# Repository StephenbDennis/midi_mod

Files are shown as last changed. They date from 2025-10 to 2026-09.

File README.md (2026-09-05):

# Github Pages
https://stephenbdennis.github.io/midi_mod/

# Modular USB MIDI Controller (Midi-Mod)

A **USB MIDI device** that supports up to **3 hot-swappable input modules**, configurable as **buttons**, **sliders**, or **potentiometers**.  
I was going for a compact design that allowed the user to configure their Midi-Mod device without needing firmware updates.
* Note: This is a work in progress... It's working, but there are many things that could be improved.

---

## Configure it in a browser

**[stephenbdennis.github.io/midi_mod](https://stephenbdennis.github.io/midi_mod/)**

Pick a message for every input and watch the MIDI bytes it will put on the wire. There is a preset
per module type (Buttons, Sliders, Pots), it imports a config you already have, and it can listen to
the device over Web MIDI so you can check what it is actually sending. Everything runs in the
browser; nothing is uploaded.

**Connect** pairs with the device over Bluetooth. From there **Load from device** pulls the config
that is on it right now, and **Send to device** writes `config.toml` back and applies it
immediately &mdash; no replug, and the device stays a USB MIDI interface throughout, so you can keep
playing into a DAW while you edit. Transfers are checksummed in both directions and rejected if they
do not match.

Bluetooth needs Web Bluetooth, so it is Chrome, Edge and Opera only (on Linux you may have to enable
it in `chrome://flags`). Everywhere else, Download still gives you the same `config.toml`.

---

### Project Build and Flash

Needs **ESP-IDF 5.2 or newer**. Dependencies come from `dependencies.lock`; `idf.py` fetches them
on the first build.

```
idf.py set-target esp32s3
idf.py build
idf.py -p COM<xxx> flash
idf.py -p COM<xxx> monitor
```

---

## Features

- **Up to 3 modules active at once**
- Modules can be:
  - Button Module (5 Cherry Mx buttons)
  - Slider Module (2 Linear Potentiometers)
  - Pot Module (5 Knob Potentiometers)
- Modules can be **mixed** (e.g. 3 Button Modules or 1 Button + 1 Slider + 1 Pot)
- **Every MIDI message**: notes, aftertouch, control change, program change, pitch bend, and the
  system common and real time messages
- Configurable with onboard .toml(ish) file
- BLE config service, so it can be reconfigured while it plays

---

## Module Types

Each module occupies **one slot**.  
A maximum of **3 slots** are available.

### 1. Button Module
- Defaults to a digital device when connected

### 2. Slider Module
- Defaults to an analog device when connected
- Uses dual sliders, so device 1 and 2 should have the roughly the same value. and well as 3 and 4. Device 5 is tied to ground.

### 3. Potentiometer Module
- Defaults to an analog device when connected

---

## Configuration
- The device advertises over Bluetooth LE as **MIDI-Mod** whenever it is powered. Open the
  configurator, press Connect, and pick it from the browser's device chooser. There is no config
  boot mode any more: USB is the MIDI interface full time.

- **Send to device** writes `config.toml` into the device's internal filesystem and applies it on
  the next poll tick, so a change is audible straight away.

- `reference.txt` is written to the internal filesystem on first boot. It documents the config
  format, though the same reference is on the configurator page under **Message reference**.

- If no config.toml is present the device writes the example below, so there is always something to edit.

- A line starting with `#` is a comment. Numbers are hexadecimal.

### Module Options
- press_velocity : (Optional) 0x0-0x7F : Defaults to 0x7F
  - This is the note_on/note_off message velocity. Only used with buttons
- channel 	     : (Optional) 0x0-0xF  : Defaults to 0x0
  - The channel messages are sent on. (Part of the MIDI message)
- alpha	    	 : (Optional) 0.01-0.5 : Defaults to 0.3
  - This value changes the responsivity of the input. Higher is faster, Lower is smoother but slower. Currently buttons are analog reads, so this should be pretty high when using that module
### Device Options
- device_type          : (Optional) analog,digital                 : Defaults to module type
  - Digital: triggers message_on_change on the rising edge and message_on_stop on the falling edge. 
  - Analog:  triggers message_on_change when value is changing and message_on_stop when the value is no longer changing. 
- channel              : (Optional) 0x0-0xF,inherit                : Defaults to inherit
  - Overrides the module channel for this one input. System messages ignore it.
- message_on_change    : (Optional) see Messages below             : Defaults to noop
  - The message to send when the value changes (analog) or rising edge (digital). This can be a name or a status byte
- message_on_stop      : (Optional) see Messages below             : Defaults to noop
  - The message to send when the value stops changing (analog) or falling edge (digital). This can be a name or a status byte
- data 	               : (Optional) notes,0x0-0x7F                 : Defaults to 0x0. 
  - For messages that carry a note, controller or program number this will be the value in the message. This can be a note string or a hex value. Overwritten by Manual Data
- manual_data_change_0 : (Optional) 0x0-0x7F,dev                   : Not used if not set
  - If set this will set the first data byte on a change action to this value. If dev, the value of the device is used 
- manual_data_change_1 : (Optional) 0x0-0x7F,dev                   : Not used if not set
  - If set this will set the second data byte on a change action to this value. If dev, the value of the device is used
- manual_data_stop_0   : (Optional) 0x0-0x7F,dev                   : Not used if not set
  - If set this will set the first data byte on a stop action to this value. If dev, the value of the device is used
- manual_data_stop_1   : (Optional) 0x0-0x7F,dev                   : Not used if not set
  - If set this will set the second data byte on a stop action to this value. If dev, the value of the device is used

### Messages

`input` is the live 0-127 reading of the button, slider or knob. `data` is the device's `data` option.

| Name | Status | Bytes | Data 1 | Data 2 |
| --- | --- | --- | --- | --- |
| `noop` | - | 0 | nothing is sent | |
| `note_off` | 0x80 | 3 | note (data) | velocity (press_velocity) |
| `note_on` | 0x90 | 3 | note (data) | velocity (press_velocity) |
| `poly_aftertouch` | 0xA0 | 3 | note (data) | pressure (input) |
| `cc` | 0xB0 | 3 | controller (data) | value (input) |
| `pc` | 0xC0 | 2 | program (data) | |
| `channel_aftertouch` | 0xD0 | 2 | pressure (input) | |
| `pitch_bend` | 0xE0 | 3 | bend LSB (input) | bend MSB (input) |
| `mtc_quarter_frame` | 0xF1 | 2 | time code (data) | |
| `song_position` | 0xF2 | 3 | position LSB (input) | position MSB (input) |
| `song_select` | 0xF3 | 2 | song (data) | |
| `tune_request` | 0xF6 | 1 | | |
| `clock` | 0xF8 | 1 | | |
| `start` | 0xFA | 1 | | |
| `continue` | 0xFB | 1 | | |
| `stop` | 0xFC | 1 | | |
| `active_sensing` | 0xFE | 1 | | |
| `system_reset` | 0xFF | 1 | | |

- Aliases: `control_change` = `cc`, `program_change` = `pc`, `channel_pressure` = `channel_aftertouch`, `timing_clock` = `clock`
- A raw status byte such as `0x90` works in place of a name
- Messages from 0xF1 up are system messages and ignore the channel
- `pitch_bend` and `song_position` spread the 0-127 reading across their full 14 bit range

### Notes
`C_(-1..9)` `C#_(-1..9)` `D_(-1..9)` `D#_(-1..9)` `E_(-1..9)` `F_(-1..9)` `F#_(-1..9)` `G_(-1..9)` `G#_(-1..8)` `A_(-1..8)` `A#_(-1..8)` `B_(-1..8)`

### Example
```
[module1]
channel = 0x0
press_velocity = 0x7F
alpha = 0.5
[module1.device1]
message_on_change = note_on
message_on_stop = note_off
data = C_3
[module1.device2]
message_on_change = note_on
message_on_stop = note_off
data = D_3
[module1.device3]
message_on_change = note_on
message_on_stop = note_off
data = E_3
[module1.device4]
message_on_change = start
message_on_stop = stop
[module1.device5]
message_on_change = pc
data = 0x0

[module2]
channel = 0x0
alpha = 0.3
[module2.device1]
message_on_change = cc
data = 0x1
[module2.device2]
message_on_change = cc
data = 0x7
[module2.device3]
message_on_change = cc
data = 0xA
[module2.device4]
message_on_change = pitch_bend
[module2.device5]
message_on_change = channel_aftertouch

[module3]
channel = 0x1
alpha = 0.3
[module3.device1]
message_on_change = cc
data = 0x0
[module3.device2]
message_on_change = cc
data = 0x2
[module3.device3]
message_on_change = poly_aftertouch
data = C_3
[module3.device4]
message_on_change = cc
data = 0x4
[module3.device5]
message_on_change = cc
data = 0x5
```

---

## Repo layout

| Path | What it is |
| --- | --- |
| `main/` | ESP32-S3 firmware |
| `boards/` | KiCad projects for the main board and the three module types |
| `docs/` | The web configurator, published to GitHub Pages |
| `.github/workflows/pages.yml` | Deploys `docs/` on every push to `main` |

To turn the page on, set **Settings → Pages → Source** to **GitHub Actions**. (Deploying from the
`main` branch `/docs` folder works too, and needs no workflow.)

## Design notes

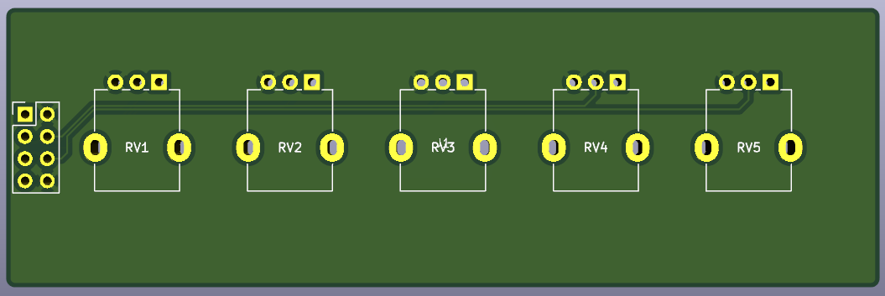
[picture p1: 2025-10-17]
images/midi-pot.png

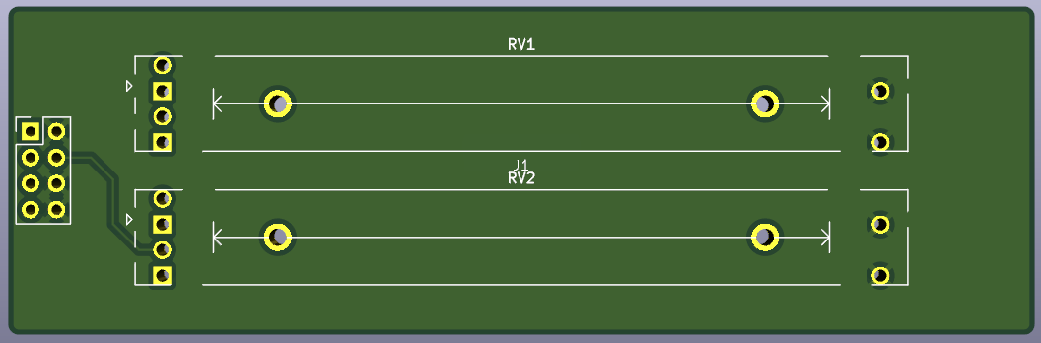
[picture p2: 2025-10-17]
images/midi-slide.png

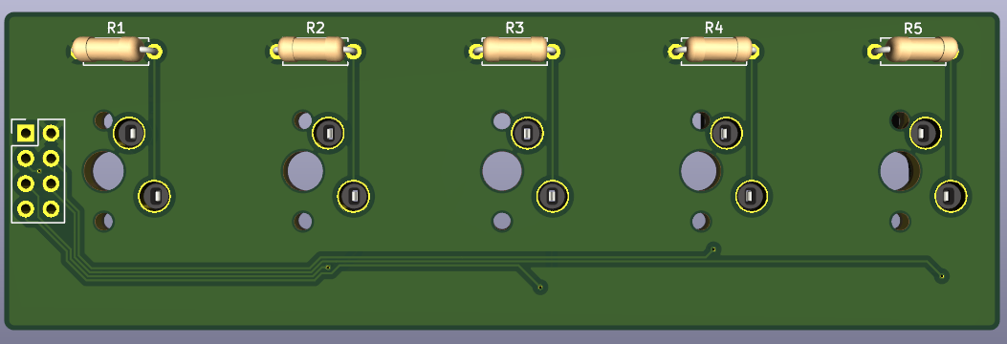
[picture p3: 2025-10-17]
images/midi-button.png

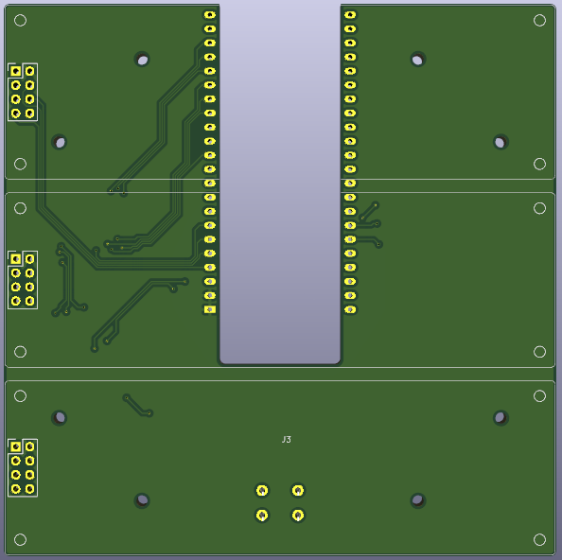
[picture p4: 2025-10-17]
images/midi-main.png

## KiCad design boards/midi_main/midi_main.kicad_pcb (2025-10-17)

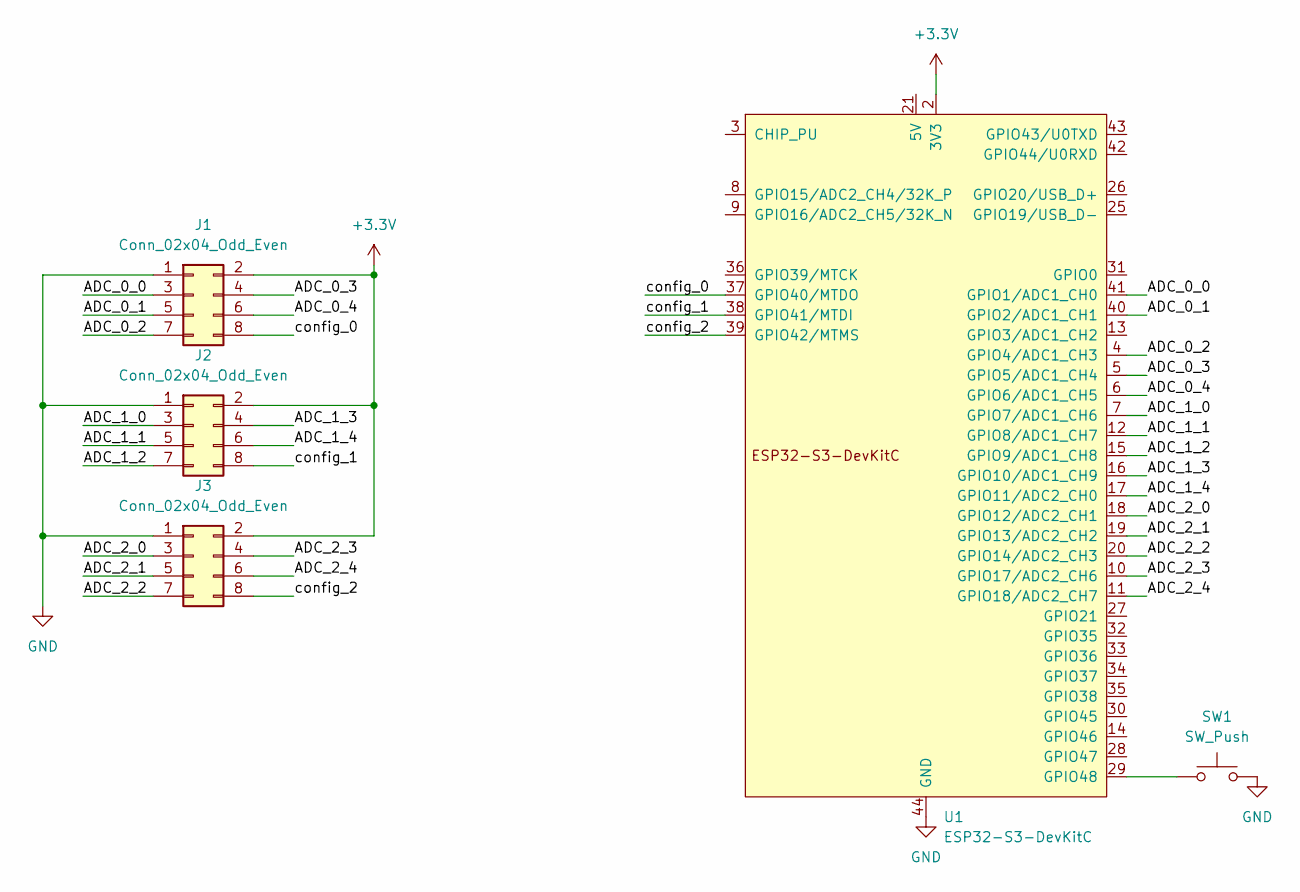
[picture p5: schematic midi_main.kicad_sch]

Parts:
J1, J2, J3: Conn_02x04_Odd_Even; MidiModuleOutline
SW1: SW_Push; SW_PUSH_6mm_H7.3mm
U1: ESP32-S3-DevKitC; ESP32-S3-DevKitC_Steve

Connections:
+3.3V: J1.2, J2.2, J3.2, U1.1 (3V3), U1.2 (3V3)
/ADC_0_0: J1.3, U1.41 (GPIO1/ADC1_CH0)
/ADC_0_1: J1.5, U1.40 (GPIO2/ADC1_CH1)
/ADC_0_2: J1.7, U1.4 (GPIO4/ADC1_CH3)
/ADC_0_3: J1.4, U1.5 (GPIO5/ADC1_CH4)
/ADC_0_4: J1.6, U1.6 (GPIO6/ADC1_CH5)
/ADC_1_0: J2.3, U1.7 (GPIO7/ADC1_CH6)
/ADC_1_1: J2.5, U1.12 (GPIO8/ADC1_CH7)
/ADC_1_2: J2.7, U1.15 (GPIO9/ADC1_CH8)
/ADC_1_3: J2.4, U1.16 (GPIO10/ADC1_CH9)
/ADC_1_4: J2.6, U1.17 (GPIO11/ADC2_CH0)
/ADC_2_0: J3.3, U1.18 (GPIO12/ADC2_CH1)
/ADC_2_1: J3.5, U1.19 (GPIO13/ADC2_CH2)
/ADC_2_2: J3.7, U1.20 (GPIO14/ADC2_CH3)
/ADC_2_3: J3.4, U1.10 (GPIO17/ADC2_CH6)
/ADC_2_4: J3.6, U1.11 (GPIO18/ADC2_CH7)
/config_0: J1.8, U1.37 (GPIO40/MTDO)
/config_1: J2.8, U1.38 (GPIO41/MTDI)
/config_2: J3.8, U1.39 (GPIO42/MTMS)
GND: J1.1, J2.1, J3.1, SW1.2, U1.22 (GND), U1.23 (GND), U1.24 (GND), U1.44 (GND)
unnamed: SW1.1, U1.29 (GPIO48)

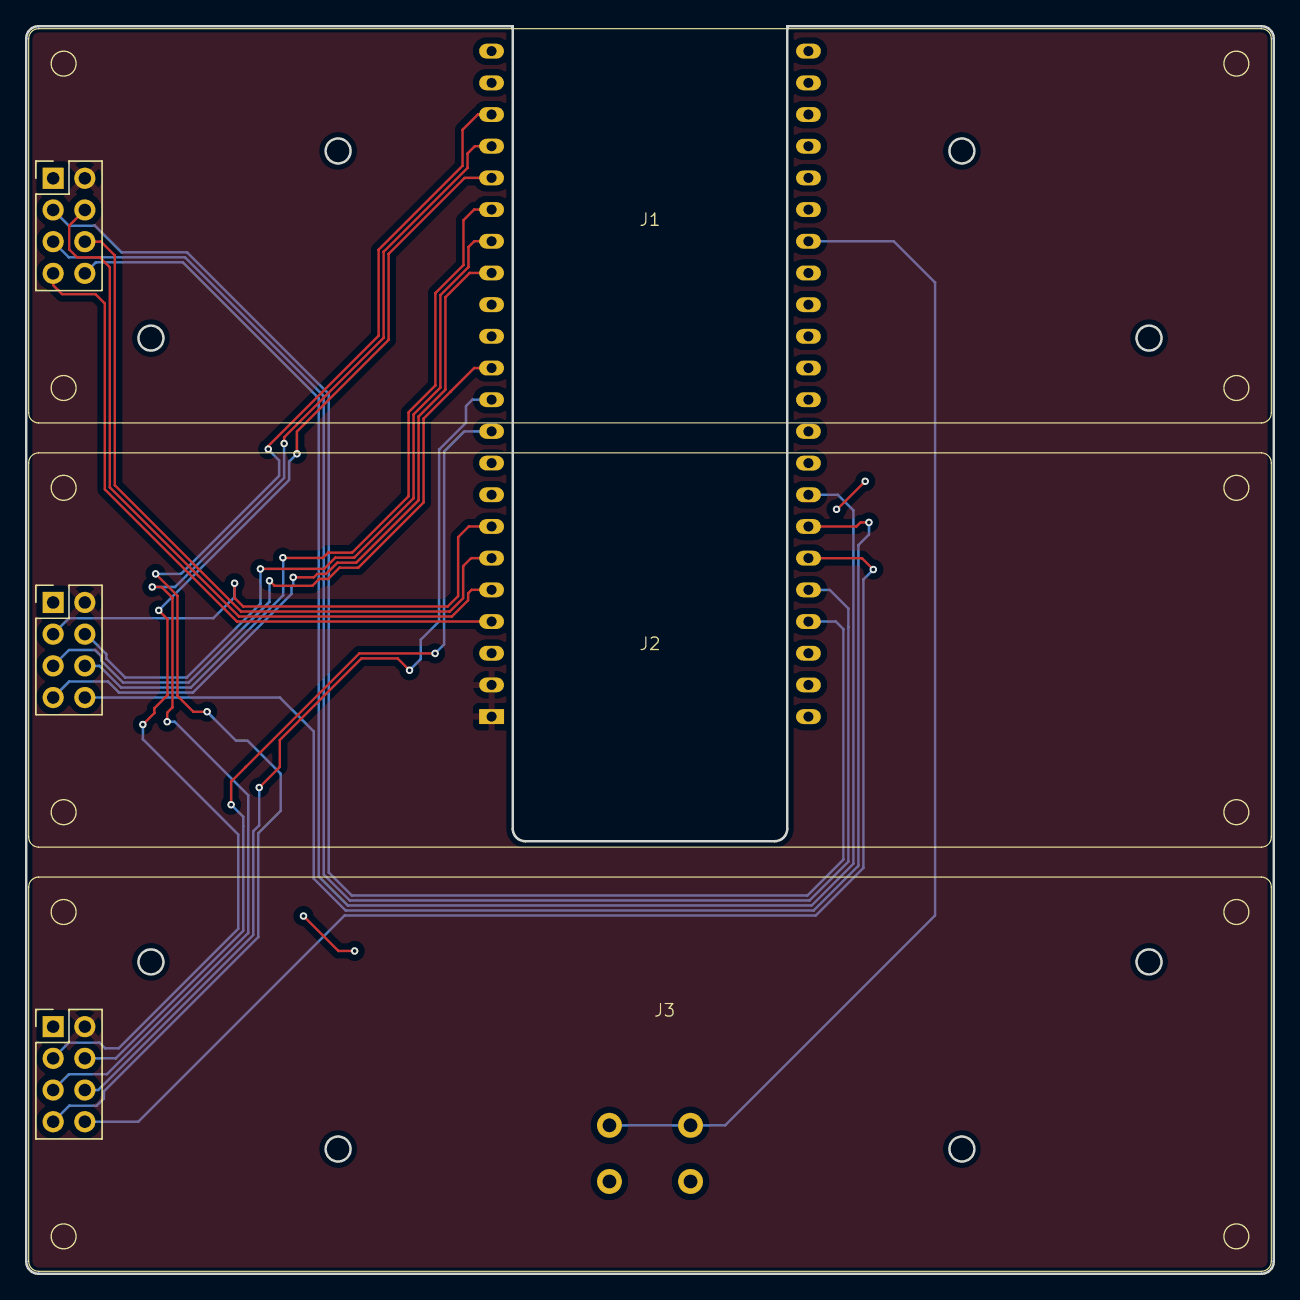
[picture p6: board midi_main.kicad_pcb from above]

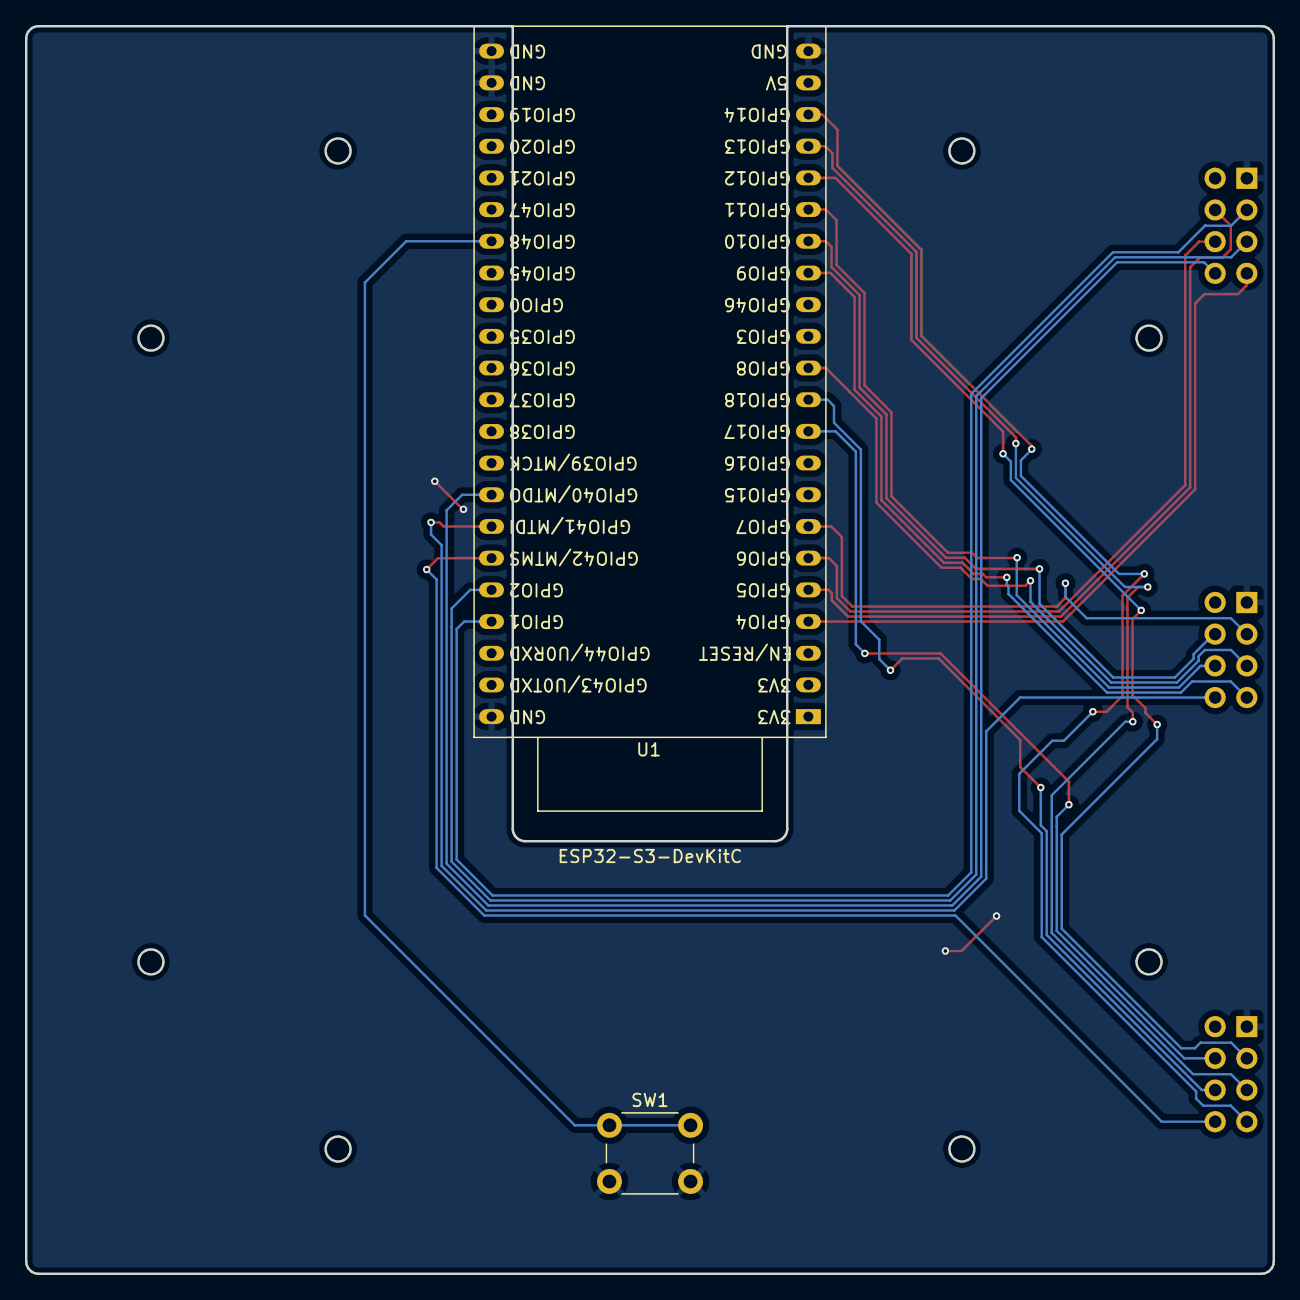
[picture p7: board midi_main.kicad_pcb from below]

Board: 2 copper layers, 100.0 x 100.0 mm, 5 parts (2 on the bottom side), 21 nets.

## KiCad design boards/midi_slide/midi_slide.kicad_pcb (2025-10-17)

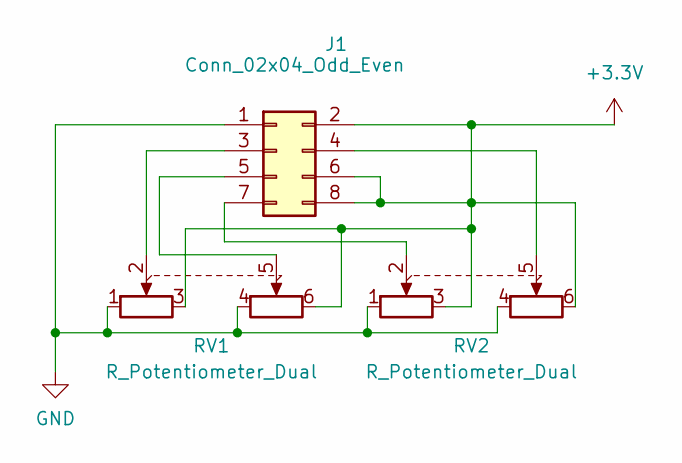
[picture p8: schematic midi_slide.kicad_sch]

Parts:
J1: Conn_02x04_Odd_Even; MidiModuleBase
RV1, RV2: R_Potentiometer_Dual; PS60M-0MC2BR10KN

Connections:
+3.3V: J1.2, J1.6, J1.8, RV1.3, RV1.6, RV2.3, RV2.6
GND: J1.1, RV1.1, RV1.4, RV2.1, RV2.4
unnamed: J1.3, RV1.2
unnamed: J1.4, RV2.5
unnamed: J1.5, RV1.5
unnamed: J1.7, RV2.2

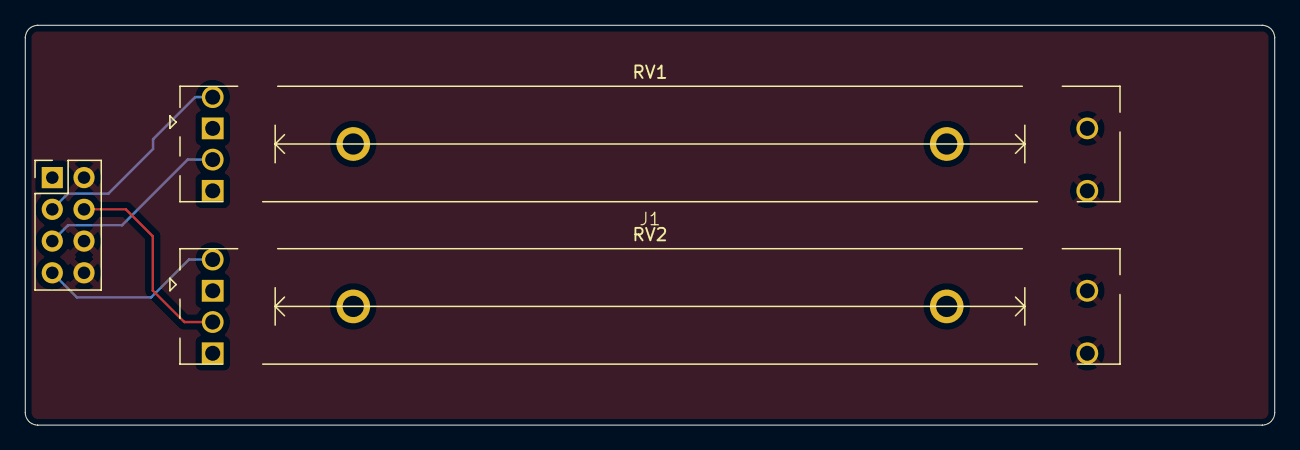
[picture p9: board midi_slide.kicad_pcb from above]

Board: 2 copper layers, 100.0 x 32.0 mm, 3 parts (0 on the bottom side), 6 nets.

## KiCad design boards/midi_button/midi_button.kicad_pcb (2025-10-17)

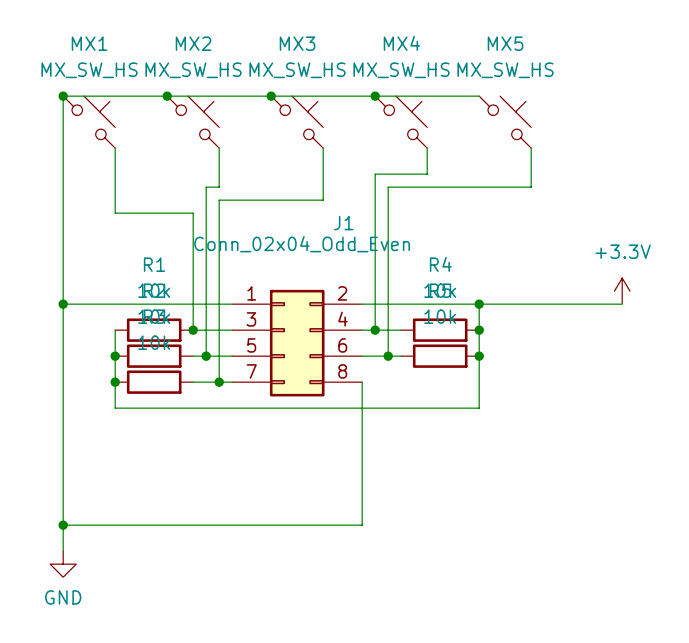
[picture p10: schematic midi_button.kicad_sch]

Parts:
J1: Conn_02x04_Odd_Even; MidiModuleBase
MX1, MX2, MX3, MX4, MX5: MX_SW_HS; SW_MX_HS_CPG151101S11_1u
R1, R2, R3, R4, R5: 10k; R_Axial_DIN0207_L6.3mm_D2.5mm_P7.62mm_Horizontal

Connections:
+3.3V: J1.2, R1.1, R2.1, R3.1, R4.2, R5.2
GND: J1.1, J1.8, MX1.1, MX2.1, MX3.1, MX4.1, MX5.1
unnamed: J1.3, MX1.2, R1.2
unnamed: J1.4, MX4.2, R4.1
unnamed: J1.5, MX2.2, R2.2
unnamed: J1.6, MX5.2, R5.1
unnamed: J1.7, MX3.2, R3.2

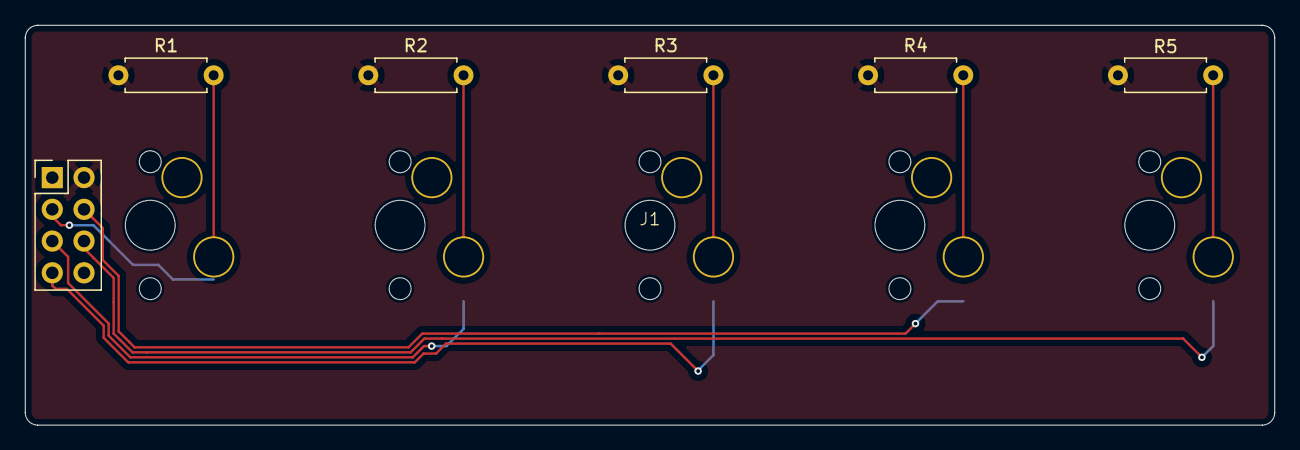
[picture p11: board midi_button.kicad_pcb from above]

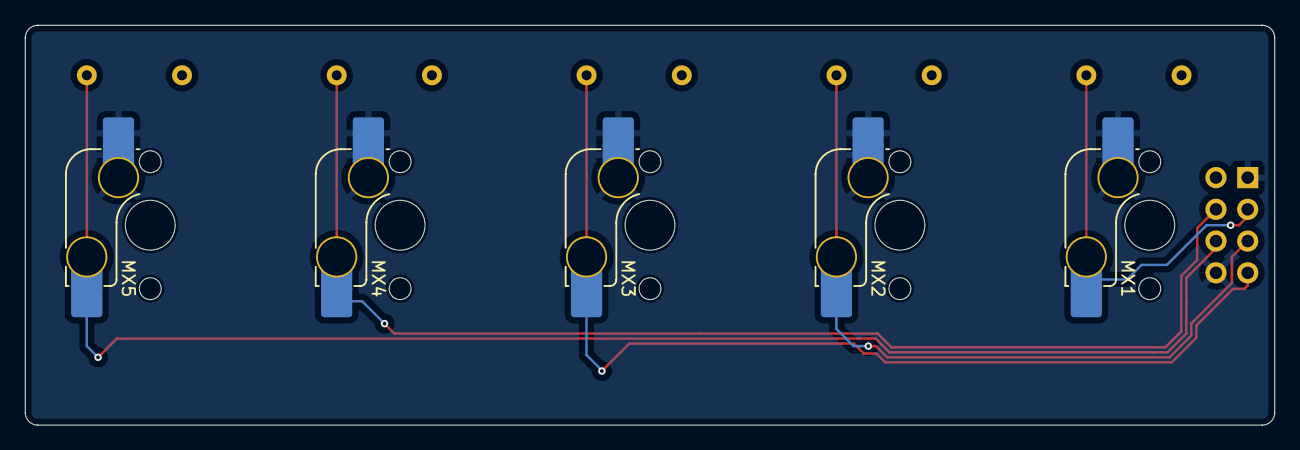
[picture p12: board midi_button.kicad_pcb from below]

Board: 2 copper layers, 100.0 x 32.0 mm, 11 parts (5 on the bottom side), 7 nets.

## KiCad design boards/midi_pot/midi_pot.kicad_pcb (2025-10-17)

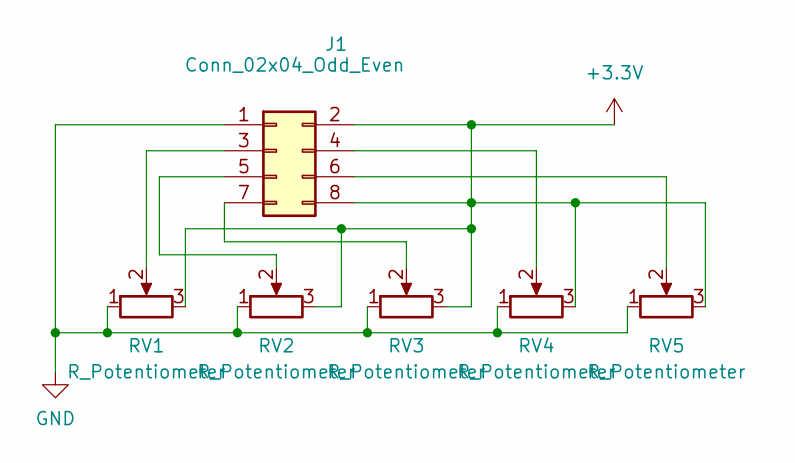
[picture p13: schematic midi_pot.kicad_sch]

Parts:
J1: Conn_02x04_Odd_Even; MidiModuleBase
RV1, RV2, RV3, RV4, RV5: R_Potentiometer; Potentiometer_Alpha_RD901F-40-00D_Single_Vertical_CENTER

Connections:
+3.3V: J1.2, J1.8, RV1.3, RV2.3, RV3.3, RV4.3, RV5.3
GND: J1.1, RV1.1, RV2.1, RV3.1, RV4.1, RV5.1
unnamed: J1.3, RV1.2
unnamed: J1.4, RV4.2
unnamed: J1.5, RV2.2
unnamed: J1.6, RV5.2
unnamed: J1.7, RV3.2

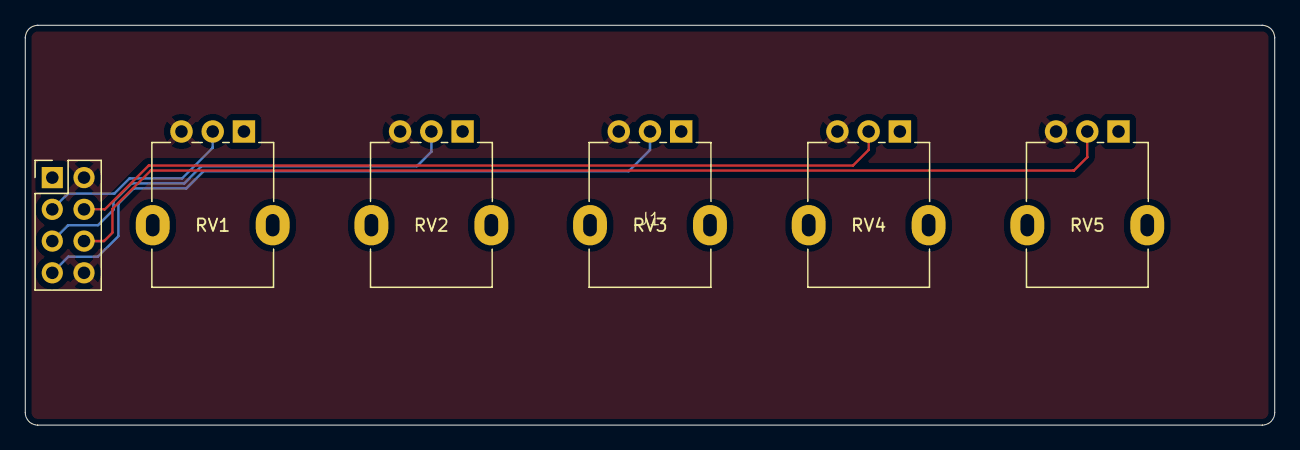
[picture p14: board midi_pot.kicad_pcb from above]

Board: 2 copper layers, 100.0 x 32.0 mm, 6 parts (0 on the bottom side), 7 nets.

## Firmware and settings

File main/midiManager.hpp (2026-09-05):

#include <stdlib.h>
#include <atomic>
#include <vector>
#include <unordered_map>
#include "driver/gpio.h"
#include "esp_adc/adc_oneshot.h"
#include "esp_adc/adc_cali.h"
#include "esp_adc/adc_cali_scheme.h"
#include "tinyusb.h"
#include "tinyusb_default_config.h"
#include "deviceInfo.hpp"

// --- Pin Mapping ---
// Common
#define MAIN_LED                GPIO_NUM_38     // GPIO38

// Device 1
#define ADC_0_0                 ADC_CHANNEL_0   // GPIO1
#define ADC_0_1                 ADC_CHANNEL_1   // GPIO2
#define ADC_0_2                 ADC_CHANNEL_3   // GPIO4
#define ADC_0_3                 ADC_CHANNEL_4   // GPIO5
#define ADC_0_4                 ADC_CHANNEL_5   // GPIO6
#define GPIO_DEVICE_1_SELECT    GPIO_NUM_40     // GPIO40

// Device 2
#define ADC_1_0                 ADC_CHANNEL_6   // GPIO7
#define ADC_1_1                 ADC_CHANNEL_7   // GPIO8
#define ADC_1_2                 ADC_CHANNEL_8   // GPIO9
#define ADC_1_3                 ADC_CHANNEL_9   // GPIO10
#define ADC_1_4                 ADC_CHANNEL_0   // GPIO11
#define GPIO_DEVICE_2_SELECT    GPIO_NUM_41     // GPIO41

// Device 3
#define ADC_2_0                 ADC_CHANNEL_1   // GPIO12
#define ADC_2_1                 ADC_CHANNEL_2   // GPIO13
#define ADC_2_2                 ADC_CHANNEL_3   // GPIO14
#define ADC_2_3                 ADC_CHANNEL_6   // GPIO17
#define ADC_2_4                 ADC_CHANNEL_7   // GPIO18
#define GPIO_DEVICE_3_SELECT    GPIO_NUM_42     // GPIO42

// TinyUSB Settings
#define TUSB_DESCRIPTOR_TOTAL_LEN (TUD_CONFIG_DESC_LEN + CFG_TUD_MIDI * TUD_MIDI_DESC_LEN)

// ADC handles
static adc_oneshot_unit_handle_t adc_1_handle;
static adc_oneshot_unit_handle_t adc_2_handle;

// ADC config
static adc_oneshot_unit_init_cfg_t init_1_config = 
{
  .unit_id = ADC_UNIT_1,
  .ulp_mode = ADC_ULP_MODE_DISABLE
};
static adc_oneshot_unit_init_cfg_t init_2_config = 
{
  .unit_id = ADC_UNIT_2,
  .ulp_mode = ADC_ULP_MODE_DISABLE
};

enum interface_count
{
#if CFG_TUD_MIDI
  ITF_NUM_MIDI = 0,
  ITF_NUM_MIDI_STREAMING,
#endif
  ITF_COUNT
};

enum usb_endpoints
{
  EP_EMPTY = 0,
#if CFG_TUD_MIDI
  EPNUM_MIDI,
#endif
};

static const uint8_t s_midi_cfg_desc[] =
{
  // Configuration number, interface count, string index, total length, attribute, power in mA
  TUD_CONFIG_DESCRIPTOR(1, ITF_COUNT, 0, TUSB_DESCRIPTOR_TOTAL_LEN, 0, 100),

  // Interface number, string index, EP Out & EP In address, EP size
  TUD_MIDI_DESCRIPTOR(ITF_NUM_MIDI, 4, EPNUM_MIDI, (0x80 | EPNUM_MIDI), 64),
};

#if (TUD_OPT_HIGH_SPEED)
static const uint8_t s_midi_hs_cfg_desc[] =
{
  // Configuration number, interface count, string index, total length, attribute, power in mA
  TUD_CONFIG_DESCRIPTOR(1, ITF_COUNT, 0, TUSB_DESCRIPTOR_TOTAL_LEN, 0, 100),

  // Interface number, string index, EP Out & EP In address, EP size
  TUD_MIDI_DESCRIPTOR(ITF_NUM_MIDI, 4, EPNUM_MIDI, (0x80 | EPNUM_MIDI), 512),
};
#endif // TUD_OPT_HIGH_SPEED

class MidiManager
{
  public:
    void updateStates(bool initial);
    void init(Config config);
    void handleUpdates();
    uint8_t scale(int value);
    void sendMidiMsg(uint8_t moduleIndex, uint8_t deviceIndex, bool changing);

    // A config synced over BLE arrives on the NimBLE worker task while the
    // poll timer is reading m_config. Staging it and picking it up at the top
    // of a tick keeps the swap off the hot path and away from a torn read.
    void stageConfig(const Config& config);
    void applyPendingConfig();

    Config m_config{};
    State m_lastState{};
    State m_curState{};

  private:
    Config m_pending{};
    std::atomic<bool> m_hasPending{false};
};

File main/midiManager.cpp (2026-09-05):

#include "midiManager.hpp"
#include "esp_log.h"

void MidiManager::updateStates(bool initial)
{
  int value = 0;
  ESP_ERROR_CHECK(adc_oneshot_read(adc_1_handle, ADC_0_0, &value));
  m_curState.modules[0].values[0] += m_config.modules[0].m_alpha * (scale(value) - m_curState.modules[0].values[0]);
  ESP_ERROR_CHECK(adc_oneshot_read(adc_1_handle, ADC_0_1, &value));
  m_curState.modules[0].values[1] += m_config.modules[0].m_alpha * (scale(value) - m_curState.modules[0].values[1]);
  ESP_ERROR_CHECK(adc_oneshot_read(adc_1_handle, ADC_0_2, &value));
  m_curState.modules[0].values[2] += m_config.modules[0].m_alpha * (scale(value) - m_curState.modules[0].values[2]);
  ESP_ERROR_CHECK(adc_oneshot_read(adc_1_handle, ADC_0_3, &value));
  m_curState.modules[0].values[3] += m_config.modules[0].m_alpha * (scale(value) - m_curState.modules[0].values[3]);
  ESP_ERROR_CHECK(adc_oneshot_read(adc_1_handle, ADC_0_4, &value));
  m_curState.modules[0].values[4] += m_config.modules[0].m_alpha * (scale(value) - m_curState.modules[0].values[4]);
  
  ESP_ERROR_CHECK(adc_oneshot_read(adc_1_handle, ADC_1_0, &value));
  m_curState.modules[1].values[0] += m_config.modules[1].m_alpha * (scale(value) - m_curState.modules[1].values[0]);
  ESP_ERROR_CHECK(adc_oneshot_read(adc_1_handle, ADC_1_1, &value));
  m_curState.modules[1].values[1] += m_config.modules[1].m_alpha * (scale(value) - m_curState.modules[1].values[1]);
  ESP_ERROR_CHECK(adc_oneshot_read(adc_1_handle, ADC_1_2, &value));
  m_curState.modules[1].values[2] += m_config.modules[1].m_alpha * (scale(value) - m_curState.modules[1].values[2]);
  ESP_ERROR_CHECK(adc_oneshot_read(adc_1_handle, ADC_1_3, &value));
  m_curState.modules[1].values[3] += m_config.modules[1].m_alpha * (scale(value) - m_curState.modules[1].values[3]);
  ESP_ERROR_CHECK(adc_oneshot_read(adc_2_handle, ADC_1_4, &value));
  m_curState.modules[1].values[4] += m_config.modules[1].m_alpha * (scale(value) - m_curState.modules[1].values[4]);
  
  ESP_ERROR_CHECK(adc_oneshot_read(adc_2_handle, ADC_2_0, &value));
  m_curState.modules[2].values[0] += m_config.modules[2].m_alpha * (scale(value) - m_curState.modules[2].values[0]);
  ESP_ERROR_CHECK(adc_oneshot_read(adc_2_handle, ADC_2_1, &value));
  m_curState.modules[2].values[1] += m_config.modules[2].m_alpha * (scale(value) - m_curState.modules[2].values[1]);
  ESP_ERROR_CHECK(adc_oneshot_read(adc_2_handle, ADC_2_2, &value));
  m_curState.modules[2].values[2] += m_config.modules[2].m_alpha * (scale(value) - m_curState.modules[2].values[2]);
  ESP_ERROR_CHECK(adc_oneshot_read(adc_2_handle, ADC_2_3, &value));
  m_curState.modules[2].values[3] += m_config.modules[2].m_alpha * (scale(value) - m_curState.modules[2].values[3]);
  ESP_ERROR_CHECK(adc_oneshot_read(adc_2_handle, ADC_2_4, &value));
  m_curState.modules[2].values[4] += m_config.modules[2].m_alpha * (scale(value) - m_curState.modules[2].values[4]);

  m_curState.modules[0].moduleSelect = gpio_get_level(GPIO_DEVICE_1_SELECT);
  m_curState.modules[1].moduleSelect = gpio_get_level(GPIO_DEVICE_2_SELECT);
  m_curState.modules[2].moduleSelect = gpio_get_level(GPIO_DEVICE_3_SELECT);

  if (initial)
  {
    m_lastState = m_curState;
  }
}

void MidiManager::init(Config config)
{
  m_config = config;
  // Setup USB
  tinyusb_config_t tusb_cfg = TINYUSB_DEFAULT_CONFIG();
  // descriptor.device is left NULL so the stack uses the Kconfig defaults.
  tusb_cfg.descriptor.string = tinyUsbConfig;
  tusb_cfg.descriptor.string_count = sizeof(tinyUsbConfig) / sizeof(tinyUsbConfig[0]);
  tusb_cfg.descriptor.full_speed_config = s_midi_cfg_desc;
#if (TUD_OPT_HIGH_SPEED)
  tusb_cfg.descriptor.high_speed_config = s_midi_hs_cfg_desc;
#endif // TUD_OPT_HIGH_SPEED

  ESP_ERROR_CHECK(tinyusb_driver_install(&tusb_cfg));

  // Setup GPIO. Make sure the channels are correct
  ESP_ERROR_CHECK(adc_oneshot_new_unit(&init_1_config, &adc_1_handle));
  ESP_ERROR_CHECK(adc_oneshot_new_unit(&init_2_config, &adc_2_handle));

  adc_oneshot_chan_cfg_t chan_config =
  {
    .atten = ADC_ATTEN_DB_12,  // 3.3V max
    .bitwidth = ADC_BITWIDTH_DEFAULT
  };

  ESP_ERROR_CHECK(adc_oneshot_config_channel(adc_1_handle, ADC_0_0, &chan_config));
  ESP_ERROR_CHECK(adc_oneshot_config_channel(adc_1_handle, ADC_0_1, &chan_config));
  ESP_ERROR_CHECK(adc_oneshot_config_channel(adc_1_handle, ADC_0_2, &chan_config));
  ESP_ERROR_CHECK(adc_oneshot_config_channel(adc_1_handle, ADC_0_3, &chan_config));
  ESP_ERROR_CHECK(adc_oneshot_config_channel(adc_1_handle, ADC_0_4, &chan_config));

  ESP_ERROR_CHECK(adc_oneshot_config_channel(adc_1_handle, ADC_1_0, &chan_config));
  ESP_ERROR_CHECK(adc_oneshot_config_channel(adc_1_handle, ADC_1_1, &chan_config));
  ESP_ERROR_CHECK(adc_oneshot_config_channel(adc_1_handle, ADC_1_2, &chan_config));
  ESP_ERROR_CHECK(adc_oneshot_config_channel(adc_1_handle, ADC_1_3, &chan_config));
  ESP_ERROR_CHECK(adc_oneshot_config_channel(adc_2_handle, ADC_1_4, &chan_config));

  ESP_ERROR_CHECK(adc_oneshot_config_channel(adc_2_handle, ADC_2_0, &chan_config));
  ESP_ERROR_CHECK(adc_oneshot_config_channel(adc_2_handle, ADC_2_1, &chan_config));
  ESP_ERROR_CHECK(adc_oneshot_config_channel(adc_2_handle, ADC_2_2, &chan_config));
  ESP_ERROR_CHECK(adc_oneshot_config_channel(adc_2_handle, ADC_2_3, &chan_config));
  ESP_ERROR_CHECK(adc_oneshot_config_channel(adc_2_handle, ADC_2_4, &chan_config));

  gpio_config_t device_1_select_conf =
  {
    .pin_bit_mask = 1ULL << GPIO_DEVICE_1_SELECT,
    .mode = GPIO_MODE_INPUT,
    .pull_up_en = GPIO_PULLUP_DISABLE,
    .pull_down_en = GPIO_PULLDOWN_ENABLE,
    .intr_type = GPIO_INTR_DISABLE,
  };
  ESP_ERROR_CHECK(gpio_config(&device_1_select_conf));

  gpio_config_t device_2_select_conf =
  {
    .pin_bit_mask = 1ULL << GPIO_DEVICE_2_SELECT,
    .mode = GPIO_MODE_INPUT,
    .pull_up_en = GPIO_PULLUP_DISABLE,
    .pull_down_en = GPIO_PULLDOWN_ENABLE,
    .intr_type = GPIO_INTR_DISABLE,
  };
  ESP_ERROR_CHECK(gpio_config(&device_2_select_conf));

  gpio_config_t device_3_select_conf =
  {
    .pin_bit_mask = 1ULL << GPIO_DEVICE_3_SELECT,
    .mode = GPIO_MODE_INPUT,
    .pull_up_en = GPIO_PULLUP_DISABLE,
    .pull_down_en = GPIO_PULLDOWN_ENABLE,
    .intr_type = GPIO_INTR_DISABLE,
  };
  ESP_ERROR_CHECK(gpio_config(&device_3_select_conf));
}
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

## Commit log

2025-10-17 Add boards
    [midi_button.kicad_pcb, midi_button.kicad_sch, midi_main.kicad_pcb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]
2025-12-12 msc working
    [partitions.csv]
2026-09-05 build fix, remove unneeded files
    [midiManager.cpp, midiManager.hpp]
2026-09-05 Add ble
    [partitions.csv]
